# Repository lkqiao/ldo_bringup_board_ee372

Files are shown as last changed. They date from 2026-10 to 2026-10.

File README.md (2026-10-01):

# ldo_bringup_board_ee372

LDO bring up PCB for EE372.

- 20 µF / 390 mΩ RC dominant pole compensation at VOUT
- 0.1 µF cap at the NR pin for bandgap reference noise filtering
- Switch on the MD pin to toggle between high power and low power modes

## Project libraries

Both libraries are registered in the project-local `sym-lib-table` /
`fp-lib-table` under the nickname `ldo_bringup_board_ee372`, via
`${KIPRJMOD}`, so they resolve on any clone without per-machine setup.

| File | Contents |
|---|---|
| `ldo_bringup_board_ee372.kicad_sym` | `LDO_DualMode_BGR_EE372` — 32-pin symbol + EP |
| `ldo_bringup_board_ee372.pretty/` | `QFN-32-1EP_7x7mm_P0.65mm_EP5.1x5.1mm_QuikPak` |

### Package

Quik-Pak **QP-QFN32-7MM-.65MM**, open-cavity QFN-32, rev A2. The numbers
come from the EE372B PCB Design Guidelines (Fall 2026, section 2), the
Quik-Pak mechanical drawing `QP-QFN7X7-32-650 PACKAGE.pdf` and the bonding
drawing `QP-QFN7X7-32-650 BONDING.dwg`.

| Parameter | Value | Source |
|---|---|---|
| Body | 7.000 x 7.000 mm, 0.800 tall | guidelines 2.1, package drawing |
| Leads | 32 (8/side), pitch 0.650 mm | guidelines 2.1, package drawing |
| Lead width x length | 0.300 x 0.380 mm | package drawing, bottom view |
| Lead-centre span per side | 4.550 mm | package drawing, bottom view |
| Exposed paddle (bottom) | 5.100 x 5.100 mm | package drawing, bottom view |
| Die attach surface (in the cavity) | 5.300 x 5.300 mm | bonding drawing note 3; not the land size |
| Pin-1 ID | 0.400 x 45 deg chamfer | package drawing, top view |

### Footprint

`QFN-32-1EP_7x7mm_P0.65mm_EP5.1x5.1mm_QuikPak`, checked against every
requirement in guidelines section 2.2.

| Pad size | Pitch | EP land | Courtyard |
|---|---|---|---|
| 0.30 x 0.85 mm | 0.65 mm | 5.10 x 5.10 mm | 8.26 x 8.26 mm |

- Lands extend 0.375 mm past the body edge and sit 0.475 mm from the EP land.
- 9 thermal vias, 0.3 mm drill, numbered 33 with the EP. They are tented on
  both sides because the EP has no full mask opening. Instead, 16 mask windows
  sit exactly over the 16 paste windows.
- EP paste is a 4x4 window pane at 52.5% coverage.
- Pin 1 is marked on silkscreen with a dot and a 0.4 mm chamfered corner.
- The 3D model is KiCad's stock `QFN-32-1EP_7x7mm_P0.65mm_EP5.46x5.46mm.step`,
  0.9 mm tall with a closed top. It is only for renders.

### Pinout

From the die pad map. Package pin 1 = the first pad down the **left** side,
i.e. the die orientation mark aligned to the package `PIN #1 ID`. Numbering
then runs CCW: left T→B (1-8), bottom L→R (9-16), right B→T (17-24),
top R→L (25-32). Pin 33 is the exposed pad.

| | | | |
|---|---|---|---|
| 1 VSS | 9 VDD | 17 VSS | 25 VDD |
| 2 VSS | 10 VSS | 18 VSS | 26 VDD |
| 3 VSS | 11 VSS | 19 VSS | 27 VDD |
| 4 VDD | 12 VSS | 20 VSS | 28 VSS |
| 5 IBIAS | 13 VSS | 21 VOUT | 29 MD |
| 6 VSS | 14 VSS | 22 VOUT | 30 NR |
| 7 VSS | 15 VSS | 23 VSS | 31 VSS |
| 8 VDD | 16 VDD | 24 VDD | 32 VDD |

Census: 18 × VSS, 9 × VDD, 2 × VOUT, 1 × MD, 1 × NR, 1 × IBIAS = 32.

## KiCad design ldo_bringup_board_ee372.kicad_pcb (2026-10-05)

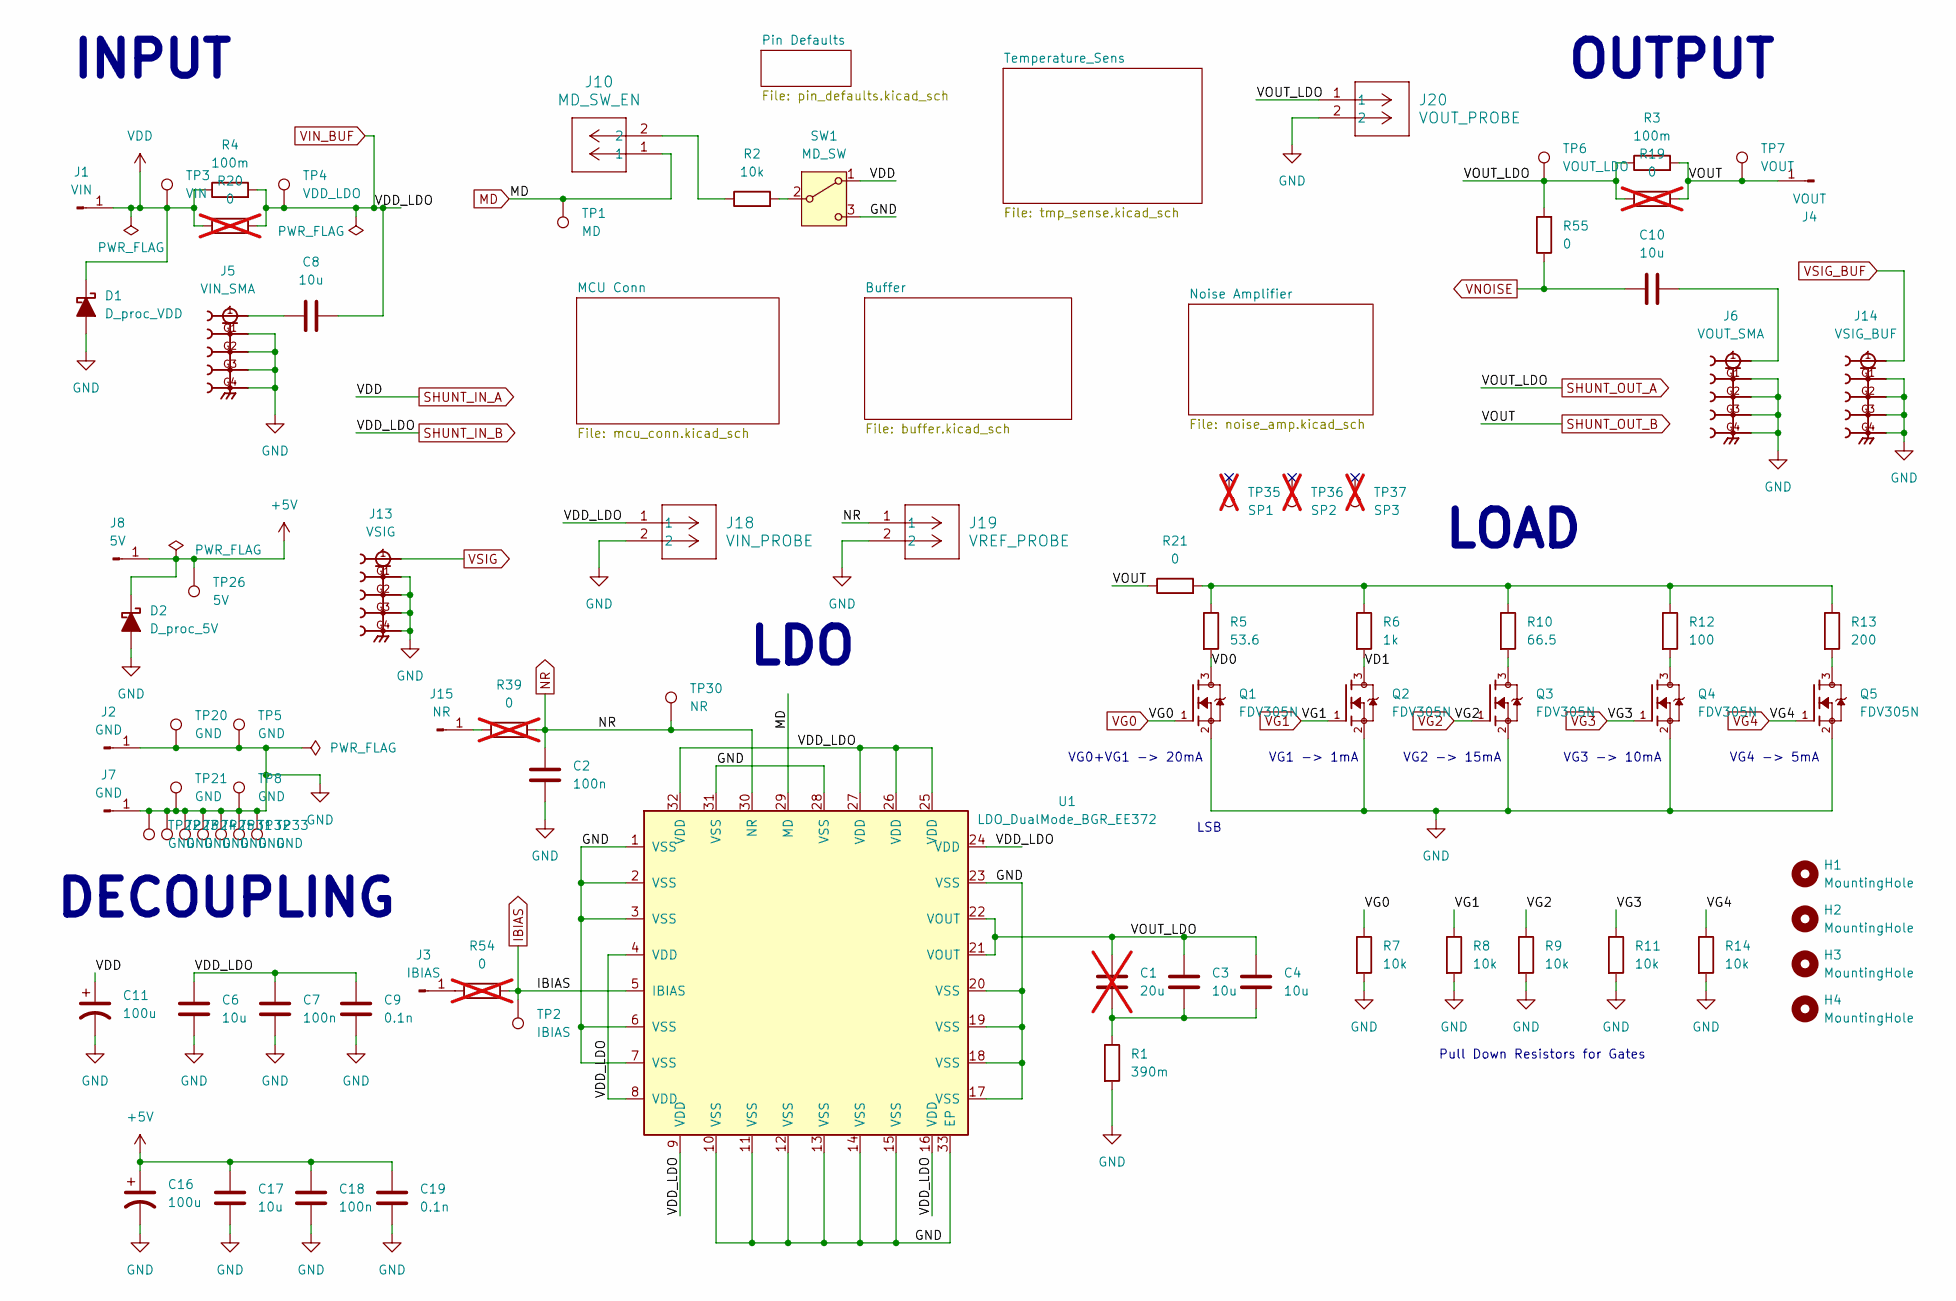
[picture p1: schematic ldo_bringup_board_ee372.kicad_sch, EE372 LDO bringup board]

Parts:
C1: 20u; C_1812_4532Metric_Pad1.57x3.40mm_HandSolder; Manufacturer Part Number C1812C206K3RLCTU; not fitted
C2, C7, C18: 100n; C_0805_2012Metric_Pad1.18x1.45mm_HandSolder; Manufacturer Part Number CL21B104KBCNNNC
C3, C4: 10u; C_1206_3216Metric_Pad1.33x1.80mm_HandSolder; Manufacturer Part Number C1206C106J3RACAUTO
C6, C8, C10, C17: 10u; C_1206_3216Metric_Pad1.33x1.80mm_HandSolder; Manufacturer Part Number GRM319R61E106KA12D
C9, C19: 0.1n; C_0805_2012Metric_Pad1.18x1.45mm_HandSolder; Manufacturer Part Number CL21C101JBANNNC
C11, C16: 100u; CP_Radial_D6.3mm_P2.50mm; Manufacturer Part Number EEU-FC1E101S
D1: D_proc_VDD; D_SMA_Handsoldering; Manufacturer Part Number B120-13-F
D2: D_proc_5V; D_SMA_Handsoldering; Manufacturer Part Number B120-13-F
H1, H2, H3, H4: MountingHole; MountingHole_3.2mm_M3
J1: VIN; CalTest_CT3151SP; Manufacturer Part Number CT3151SP-2
J2, J7: GND; CalTest_CT3151SP; Manufacturer Part Number CT3151SP-0
J3: IBIAS; CalTest_CT3151SP; Manufacturer Part Number CT3151SP-9
J4: VOUT; CalTest_CT3151SP; Manufacturer Part Number CT3151SP-4
J5: VIN_SMA; SMA_Samtec_SMA-J-P-H-ST-EM1_EdgeMount_G; Manufacturer Part Number SMA-J-P-H-ST-EM1
J6: VOUT_SMA; SMA_Samtec_SMA-J-P-H-ST-EM1_EdgeMount_G; Manufacturer Part Number SMA-J-P-H-ST-EM1
J8: 5V; CalTest_CT3151SP; Manufacturer Part Number CT3151SP-2
J10: MD_SW_EN; CONN_PxC02S_SUL; Manufacturer Part Number PEC02SAAN
J13: VSIG; SMA_Samtec_SMA-J-P-H-ST-EM1_EdgeMount_G; Manufacturer Part Number SMA-J-P-H-ST-EM1
J14: VSIG_BUF; SMA_Samtec_SMA-J-P-H-ST-EM1_EdgeMount_G; Manufacturer Part Number SMA-J-P-H-ST-EM1
J15: NR; CalTest_CT3151SP; Manufacturer Part Number CT3151SP-2
J18: VIN_PROBE; CONN_PxC02S_SUL; Manufacturer Part Number PEC02SAAN
J19: VREF_PROBE; CONN_PxC02S_SUL; Manufacturer Part Number PEC02SAAN
J20: VOUT_PROBE; CONN_PxC02S_SUL; Manufacturer Part Number PEC02SAAN
Q1, Q2, Q3, Q4, Q5: FDV305N; SOT95P240X111-3N; Manufacturer Part Number FDV305N
R1: 390m; R_0805_2012Metric_Pad1.20x1.40mm_HandSolder; Manufacturer Part Number ERJ-6BQFR39V
R2, R7, R8, R9, R11, R14: 10k; R_0805_2012Metric_Pad1.20x1.40mm_HandSolder; Manufacturer Part Number RC0805FR-0710KL
R3, R4: 100m; R_0805_2012Metric_Pad1.20x1.40mm_HandSolder; Manufacturer Part Number ERJ-6DSFR10V
R5: 53.6; R_0805_2012Metric_Pad1.20x1.40mm_HandSolder; Manufacturer Part Number RC0805FR-0753R6L
R6: 1k; R_0805_2012Metric_Pad1.20x1.40mm_HandSolder; Manufacturer Part Number RC0805FR-071KL
R10: 66.5; R_0805_2012Metric_Pad1.20x1.40mm_HandSolder; Manufacturer Part Number RC0805FR-0766R5L
R12: 100; R_0805_2012Metric_Pad1.20x1.40mm_HandSolder; Manufacturer Part Number RC0805FR-07100RL
R13: 200; R_0805_2012Metric_Pad1.20x1.40mm_HandSolder; Manufacturer Part Number RC0805FR-07200RL
R19, R20, R39, R54: 0; R_0805_2012Metric_Pad1.20x1.40mm_HandSolder; Manufacturer Part Number CRCW08050000Z0EAHP; not fitted
R21, R55: 0; R_0805_2012Metric_Pad1.20x1.40mm_HandSolder; Manufacturer Part Number CRCW08050000Z0EAHP
SW1: MD_SW; SW_SPDT_CK_JS102011SAQN; Manufacturer Part Number JS102011SAQN
TP1: MD; TestPoint_Keystone_5005-5009_Compact; Manufacturer Part Number 5005
TP2: IBIAS; TestPoint_Keystone_5005-5009_Compact; Manufacturer Part Number 5005
TP3: VIN; TestPoint_Keystone_5005-5009_Compact; Manufacturer Part Number 5005
TP4: VDD_LDO; TestPoint_Keystone_5005-5009_Compact; Manufacturer Part Number 5005
TP5, TP8, TP20, TP21, TP22, TP23, TP24, TP25, TP31, TP32, TP33: GND; TestPoint_Keystone_5005-5009_Compact; Manufacturer Part Number 5006
TP6: VOUT_LDO; TestPoint_Keystone_5005-5009_Compact; Manufacturer Part Number 5005
TP7: VOUT; TestPoint_Keystone_5005-5009_Compact; Manufacturer Part Number 5005
TP26: 5V; TestPoint_Keystone_5005-5009_Compact; Manufacturer Part Number 5005
TP30: NR; TestPoint_Keystone_5005-5009_Compact; Manufacturer Part Number 5005
TP35: SP1; TestPoint_Keystone_5005-5009_Compact; Manufacturer Part Number 5006; not fitted
TP36: SP2; TestPoint_Keystone_5005-5009_Compact; Manufacturer Part Number 5006; not fitted
TP37: SP3; TestPoint_Keystone_5005-5009_Compact; Manufacturer Part Number 5006; not fitted
U1: LDO_DualMode_BGR_EE372; QFN-32-1EP_7x7mm_P0.65mm_EP5.1x5.1mm_QuikPak

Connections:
+5V: C16.1, C17.1, C18.1, C19.1, D2.1 (K), J8.1 (Pin_1_1), TP26.1 (1_1); also elsewhere on the board
/VD0: Q1.3, R5.2
/VD1: Q2.3, R6.2
GND: C2.2, C6.2, C7.2, C9.2, C11.2, C16.2, C17.2, C18.2, C19.2, D1.2 (A), D2.2 (A), J2.1 (Pin_1_1), J5.G1, J5.G2, J5.G3, J5.G4, J6.G1, J6.G2, J6.G3, J6.G4, J7.1 (Pin_1_1), J13.G1, J13.G2, J13.G3, J13.G4, J14.G1, J14.G2, J14.G3, J14.G4, J18.2, J19.2, J20.2, Q1.2, Q2.2, Q3.2, Q4.2, Q5.2, R1.2, R7.2, R8.2, R9.2, R11.2, R14.2, SW1.3 (C), TP5.1 (1_1), TP8.1 (1_1), TP20.1 (1_1), TP21.1 (1_1), TP22.1 (1_1), TP23.1 (1_1), TP24.1 (1_1), TP25.1 (1_1), TP31.1 (1_1), TP32.1 (1_1), TP33.1 (1_1), U1.1 (VSS), U1.2 (VSS), U1.3 (VSS), U1.6 (VSS), U1.7 (VSS), U1.10 (VSS), U1.11 (VSS), U1.12 (VSS), U1.13 (VSS), U1.14 (VSS), U1.15 (VSS), U1.17 (VSS), U1.18 (VSS), U1.19 (VSS), U1.20 (VSS), U1.23 (VSS), U1.28 (VSS), U1.31 (VSS), U1.33 (EP); also elsewhere on the board
IBIAS: R54.2, TP2.1 (1_1), U1.5 (IBIAS); also elsewhere on the board
MD: J10.1, TP1.1 (1_1), U1.29 (MD); also elsewhere on the board
NR: C2.1, J19.1, R39.2, TP30.1 (1_1), U1.30 (NR); also elsewhere on the board
unnamed: C1.2, C3.2, C4.2, R1.1
unnamed: C8.1, J5.1
unnamed: C10.2, J6.1
unnamed: J3.1 (Pin_1_1), R54.1
unnamed: J10.2, R2.1
unnamed: J15.1 (Pin_1_1), R39.1
unnamed: Q3.3, R10.2
unnamed: Q4.3, R12.2
unnamed: Q5.3, R13.2
unnamed: R5.1, R6.1, R10.1, R12.1, R13.1, R21.2
unnamed: R2.2, SW1.2 (B)
SHUNT_IN_A: C11.1, D1.1 (K), J1.1 (Pin_1_1), R4.1, R20.1, SW1.1 (A), TP3.1 (1_1); also elsewhere on the board
SHUNT_IN_B: C6.1, C7.1, C8.2, C9.1, J18.1, R4.2, R20.2, TP4.1 (1_1), U1.4 (VDD), U1.8 (VDD), U1.9 (VDD), U1.16 (VDD), U1.24 (VDD), U1.25 (VDD), U1.26 (VDD), U1.27 (VDD), U1.32 (VDD); also elsewhere on the board
SHUNT_OUT_A: C1.1, C3.1, C4.1, J20.1, R3.1, R19.1, R55.2, TP6.1 (1_1), U1.21 (VOUT), U1.22 (VOUT); also elsewhere on the board
SHUNT_OUT_B: J4.1 (Pin_1_1), R3.2, R19.2, R21.1, TP7.1 (1_1); also elsewhere on the board
VG0: Q1.1, R7.1; also elsewhere on the board
VG1: Q2.1, R8.1; also elsewhere on the board
VG2: Q3.1, R9.1; also elsewhere on the board
VG3: Q4.1, R11.1; also elsewhere on the board
VG4: Q5.1, R14.1; also elsewhere on the board
VNOISE: C10.1, R55.1; also elsewhere on the board
VSIG: J13.1; also elsewhere on the board
VSIG_BUF: J14.1; also elsewhere on the board

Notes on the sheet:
OUTPUT
VG0+VG1 -> 20mA
VG3 -> 10mA
LSB
Pull Down Resistors for Gates
VG4 -> 5mA
LOAD
VG2 -> 15mA
DECOUPLING
LDO
VG1 -> 1mA
INPUT

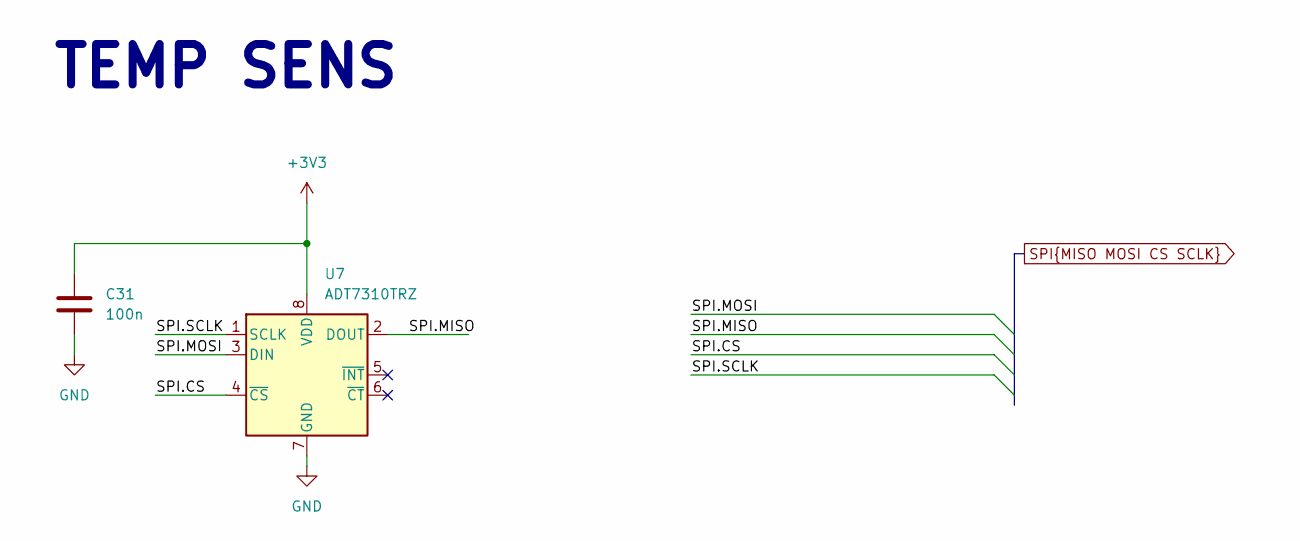
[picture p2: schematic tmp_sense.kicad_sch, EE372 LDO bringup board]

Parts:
C31: 100n; C_0805_2012Metric_Pad1.18x1.45mm_HandSolder; Manufacturer Part Number CL21B104KBCNNNC
U7: ADT7310TRZ; SOIC-8_3.9x4.9mm_P1.27mm; Manufacturer Part Number ADT7310TRZ

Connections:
+3V3: C31.1, U7.8 (VDD); also elsewhere on the board
GND: C31.2, U7.7 (GND); also elsewhere on the board
SPI.CS: U7.4 (~CS); also elsewhere on the board
SPI.MISO: U7.2 (DOUT); also elsewhere on the board
SPI.MOSI: U7.3 (DIN); also elsewhere on the board
SPI.SCLK: U7.1 (SCLK); also elsewhere on the board

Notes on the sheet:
TEMP SENS

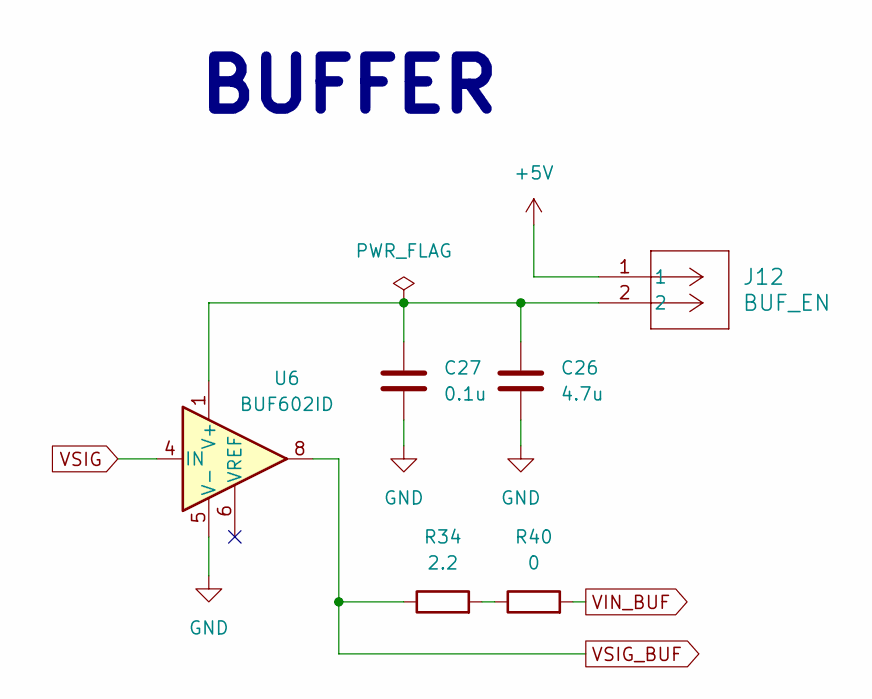
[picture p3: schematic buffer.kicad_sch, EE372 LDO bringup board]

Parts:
C26: 4.7u; C_0805_2012Metric_Pad1.18x1.45mm_HandSolder; Manufacturer Part Number CL21B475KAFNNNE
C27: 0.1u; C_0805_2012Metric_Pad1.18x1.45mm_HandSolder; Manufacturer Part Number CL21B104KBCNNNC
J12: BUF_EN; CONN_PxC02S_SUL; Manufacturer Part Number PEC02SAAN
R34: 2.2; R_0603_1608Metric_Pad0.98x0.95mm_HandSolder; Manufacturer Part Number ERJ-3RQF2R2V
R40: 0; R_0603_1608Metric_Pad0.98x0.95mm_HandSolder; Manufacturer Part Number CRCW06030000Z0EAHP
U6: BUF602ID; SOIC-8_3.9x4.9mm_P1.27mm; Manufacturer Part Number BUF602ID

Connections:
+5V: J12.1; also elsewhere on the board
GND: C26.1, C27.1, U6.5 (V-); also elsewhere on the board
unnamed: R34.2, R40.1
unnamed: C26.2, C27.2, J12.2, U6.1 (V+)
SHUNT_IN_B: R40.2; also elsewhere on the board
VSIG: U6.4 (IN); also elsewhere on the board
VSIG_BUF: R34.1, U6.8; also elsewhere on the board

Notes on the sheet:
BUFFER

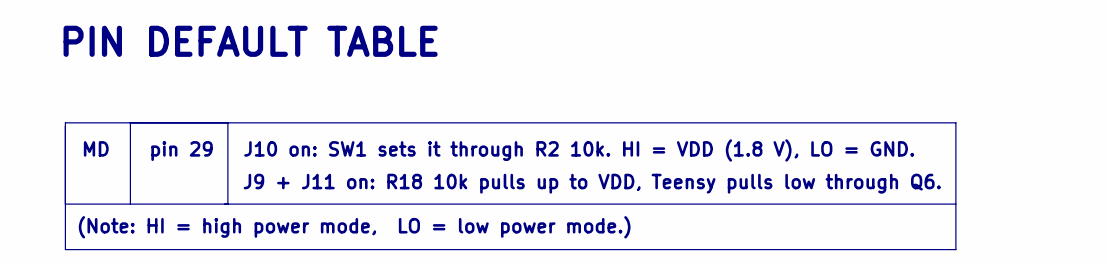
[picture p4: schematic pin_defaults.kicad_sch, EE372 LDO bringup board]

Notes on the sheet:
J9 + J11 on: R18 10k pulls up to VDD, Teensy pulls low through Q6.
(Note: HI = high power mode, LO = low power mode.)
PIN DEFAULT TABLE
MD pin 29 J10 on: SW1 sets it through R2 10k. HI = VDD (1.8 V), LO = GND.

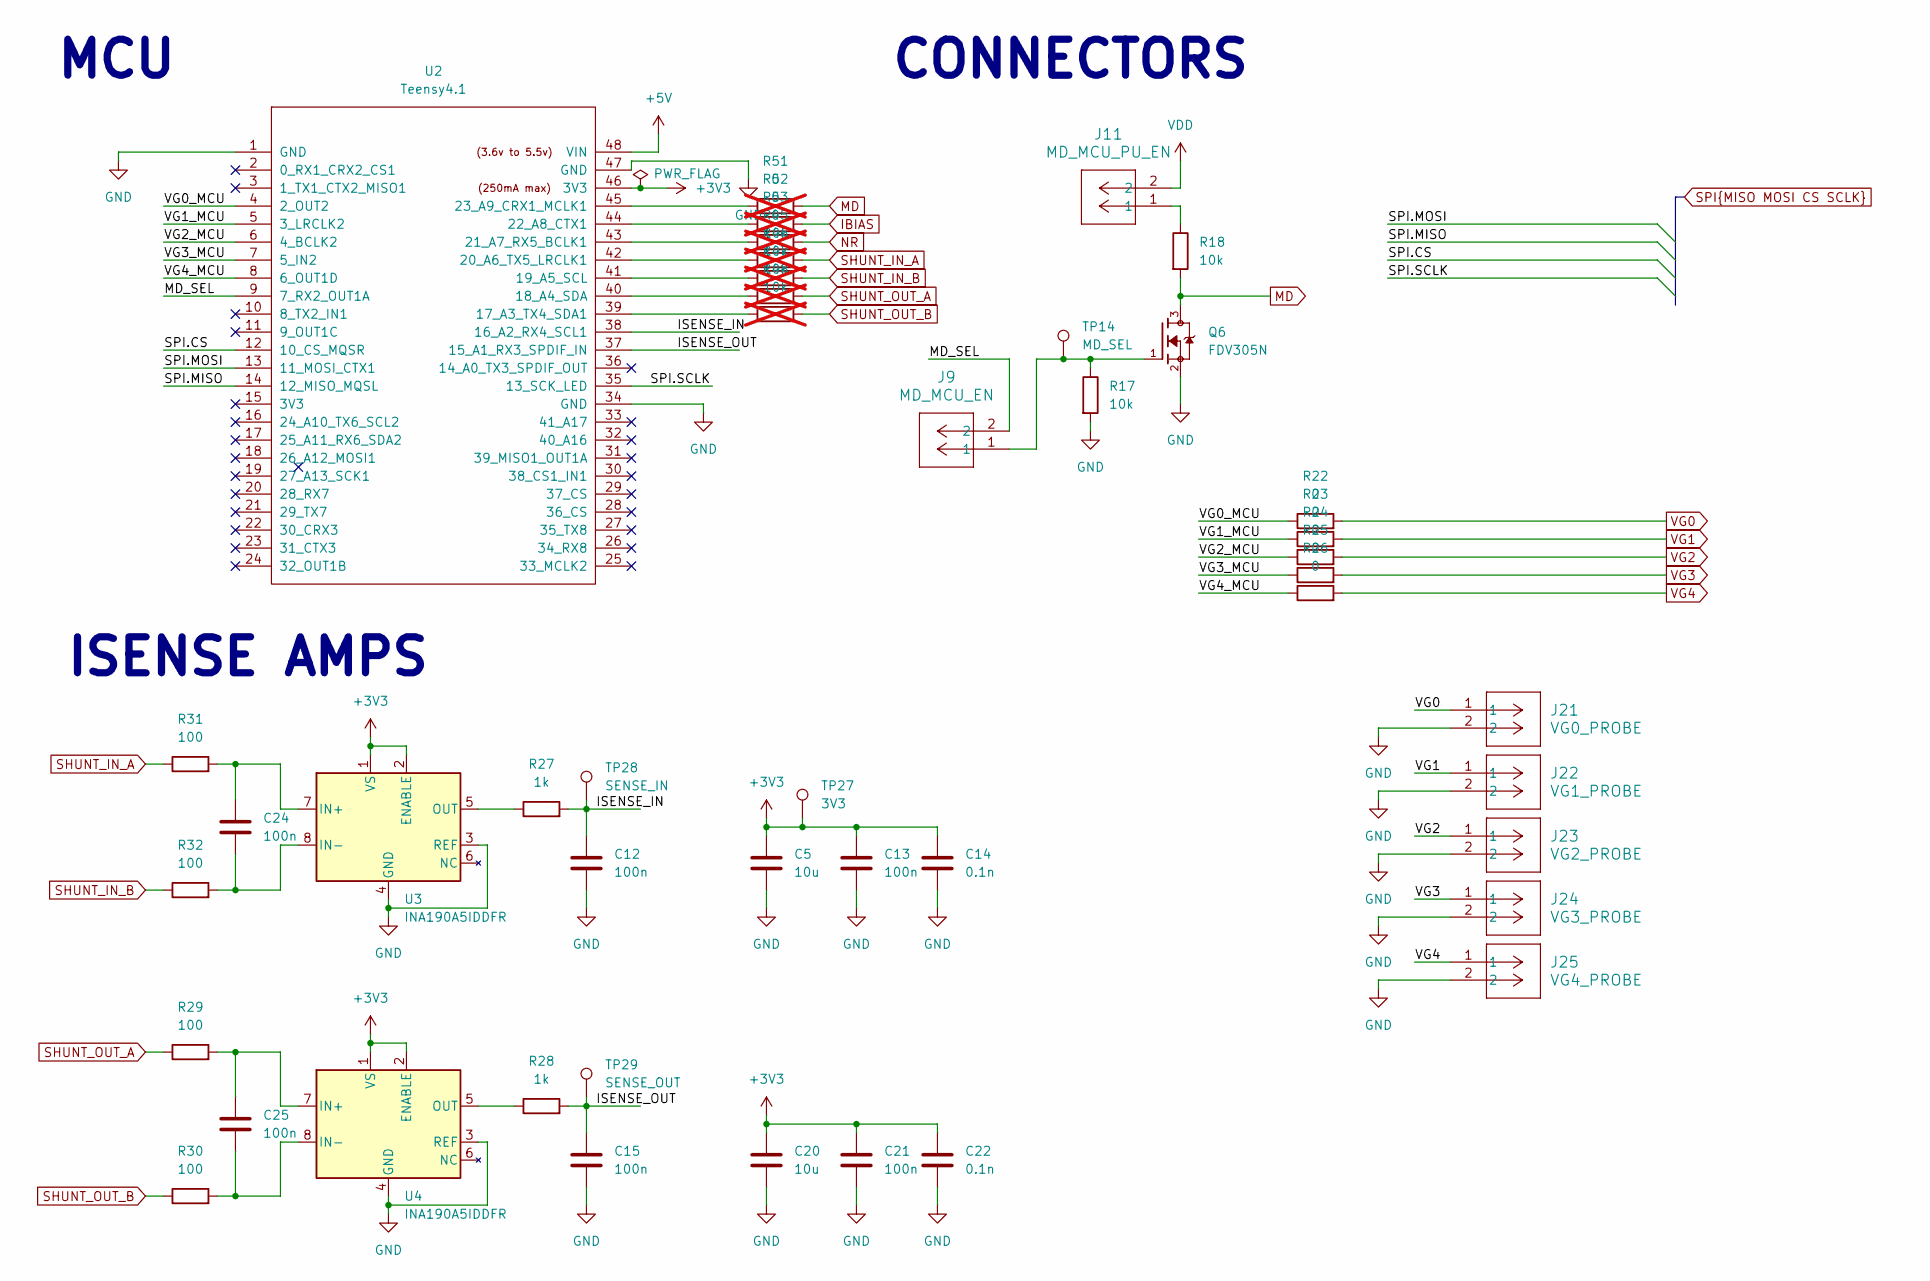
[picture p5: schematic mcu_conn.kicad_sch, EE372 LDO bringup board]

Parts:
C5, C20: 10u; C_1206_3216Metric_Pad1.33x1.80mm_HandSolder; Manufacturer Part Number GRM319R61E106KA12D
C12, C13, C15, C21, C24, C25: 100n; C_0805_2012Metric_Pad1.18x1.45mm_HandSolder; Manufacturer Part Number CL21B104KBCNNNC
C14, C22: 0.1n; C_0805_2012Metric_Pad1.18x1.45mm_HandSolder; Manufacturer Part Number CL21C101JBANNNC
J9: MD_MCU_EN; CONN_PxC02S_SUL; Manufacturer Part Number PEC02SAAN
J11: MD_MCU_PU_EN; CONN_PxC02S_SUL; Manufacturer Part Number PEC02SAAN
J21: VG0_PROBE; CONN_PxC02S_SUL; Manufacturer Part Number PEC02SAAN
J22: VG1_PROBE; CONN_PxC02S_SUL; Manufacturer Part Number PEC02SAAN
J23: VG2_PROBE; CONN_PxC02S_SUL; Manufacturer Part Number PEC02SAAN
J24: VG3_PROBE; CONN_PxC02S_SUL; Manufacturer Part Number PEC02SAAN
J25: VG4_PROBE; CONN_PxC02S_SUL; Manufacturer Part Number PEC02SAAN
Q6: FDV305N; SOT95P240X111-3N; Manufacturer Part Number FDV305N
R17, R18: 10k; R_0603_1608Metric_Pad0.98x0.95mm_HandSolder; Manufacturer Part Number RC0603FR-0710KL
R22, R23, R24, R25, R26: 0; R_0603_1608Metric_Pad0.98x0.95mm_HandSolder; Manufacturer Part Number CRCW06030000Z0EAHP
R27, R28: 1k; R_0603_1608Metric_Pad0.98x0.95mm_HandSolder; Manufacturer Part Number RC0603FR-071KL
R29, R30, R31, R32: 100; R_0603_1608Metric_Pad0.98x0.95mm_HandSolder; Manufacturer Part Number ERJ-3EKF1000V
R45, R46, R47, R48: 10k; R_0805_2012Metric_Pad1.20x1.40mm_HandSolder; Manufacturer Part Number RC0805FR-0710KL; not fitted
R51, R52, R53: 0; R_0603_1608Metric_Pad0.98x0.95mm_HandSolder; Manufacturer Part Number CRCW06030000Z0EAHP; not fitted
TP14: MD_SEL; TestPoint_Keystone_5005-5009_Compact; Manufacturer Part Number 5005
TP27: 3V3; TestPoint_Keystone_5005-5009_Compact; Manufacturer Part Number 5005
TP28: SENSE_IN; TestPoint_Keystone_5005-5009_Compact; Manufacturer Part Number 5005
TP29: SENSE_OUT; TestPoint_Keystone_5005-5009_Compact; Manufacturer Part Number 5005
U2: Teensy4.1; Teensy41_Sockets
U3, U4: INA190A5IDDFR; TSOT-23-8_HandSoldering; Manufacturer Part Number INA190A5IDDFR

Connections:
+3V3: C5.1, C13.1, C14.1, C20.1, C21.1, C22.1, TP27.1 (1_1), U2.46 (3V3), U3.1 (VS), U3.2 (ENABLE), U4.1 (VS), U4.2 (ENABLE); also elsewhere on the board
+5V: U2.48 (VIN); also elsewhere on the board
/MCU Conn/ISENSE_IN: C12.1, R27.2, TP28.1 (1_1), U2.38 (16_A2_RX4_SCL1)
/MCU Conn/ISENSE_OUT: C15.1, R28.2, TP29.1 (1_1), U2.37 (15_A1_RX3_SPDIF_IN)
/MCU Conn/MD_SEL: J9.2, U2.9 (7_RX2_OUT1A)
/MCU Conn/VG0_MCU: R22.1, U2.4 (2_OUT2)
/MCU Conn/VG1_MCU: R23.1, U2.5 (3_LRCLK2)
/MCU Conn/VG2_MCU: R24.1, U2.6 (4_BCLK2)
/MCU Conn/VG3_MCU: R25.1, U2.7 (5_IN2)
/MCU Conn/VG4_MCU: R26.1, U2.8 (6_OUT1D)
GND: C5.2, C12.2, C13.2, C14.2, C15.2, C20.2, C21.2, C22.2, J21.2, J22.2, J23.2, J24.2, J25.2, Q6.2, R17.2, U2.1 (GND), U2.34 (GND), U2.47 (GND), U3.3 (REF), U3.4 (GND), U4.3 (REF), U4.4 (GND); also elsewhere on the board
IBIAS: R52.2; also elsewhere on the board
MD: Q6.3, R18.2, R51.2; also elsewhere on the board
NR: R53.2; also elsewhere on the board
unnamed: J9.1, Q6.1, R17.1, TP14.1 (1_1)
unnamed: J11.1, R18.1
unnamed: R48.1, U2.39 (17_A3_TX4_SDA1)
unnamed: R47.1, U2.40 (18_A4_SDA)
unnamed: R46.1, U2.41 (19_A5_SCL)
unnamed: R45.1, U2.42 (20_A6_TX5_LRCLK1)
unnamed: R53.1, U2.43 (21_A7_RX5_BCLK1)
unnamed: R52.1, U2.44 (22_A8_CTX1)
unnamed: R51.1, U2.45 (23_A9_CRX1_MCLK1)
unnamed: C24.1, R31.2, U3.7 (IN+)
unnamed: C24.2, R32.2, U3.8 (IN-)
unnamed: R27.1, U3.5 (OUT)
unnamed: C25.1, R29.2, U4.7 (IN+)
unnamed: C25.2, R30.2, U4.8 (IN-)
unnamed: R28.1, U4.5 (OUT)
SHUNT_IN_A: J11.2, R31.1, R45.2; also elsewhere on the board
SHUNT_IN_B: R32.1, R46.2; also elsewhere on the board
SHUNT_OUT_A: R29.1, R47.2; also elsewhere on the board
SHUNT_OUT_B: R30.1, R48.2; also elsewhere on the board
SPI.CS: U2.12 (10_CS_MQSR); also elsewhere on the board
SPI.MISO: U2.14 (12_MISO_MQSL); also elsewhere on the board
SPI.MOSI: U2.13 (11_MOSI_CTX1); also elsewhere on the board
SPI.SCLK: U2.35 (13_SCK_LED); also elsewhere on the board
VG0: J21.1, R22.2; also elsewhere on the board
VG1: J22.1, R23.2; also elsewhere on the board
VG2: J23.1, R24.2; also elsewhere on the board
VG3: J24.1, R25.2; also elsewhere on the board
VG4: J25.1, R26.2; also elsewhere on the board

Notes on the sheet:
CONNECTORS
MCU
ISENSE AMPS

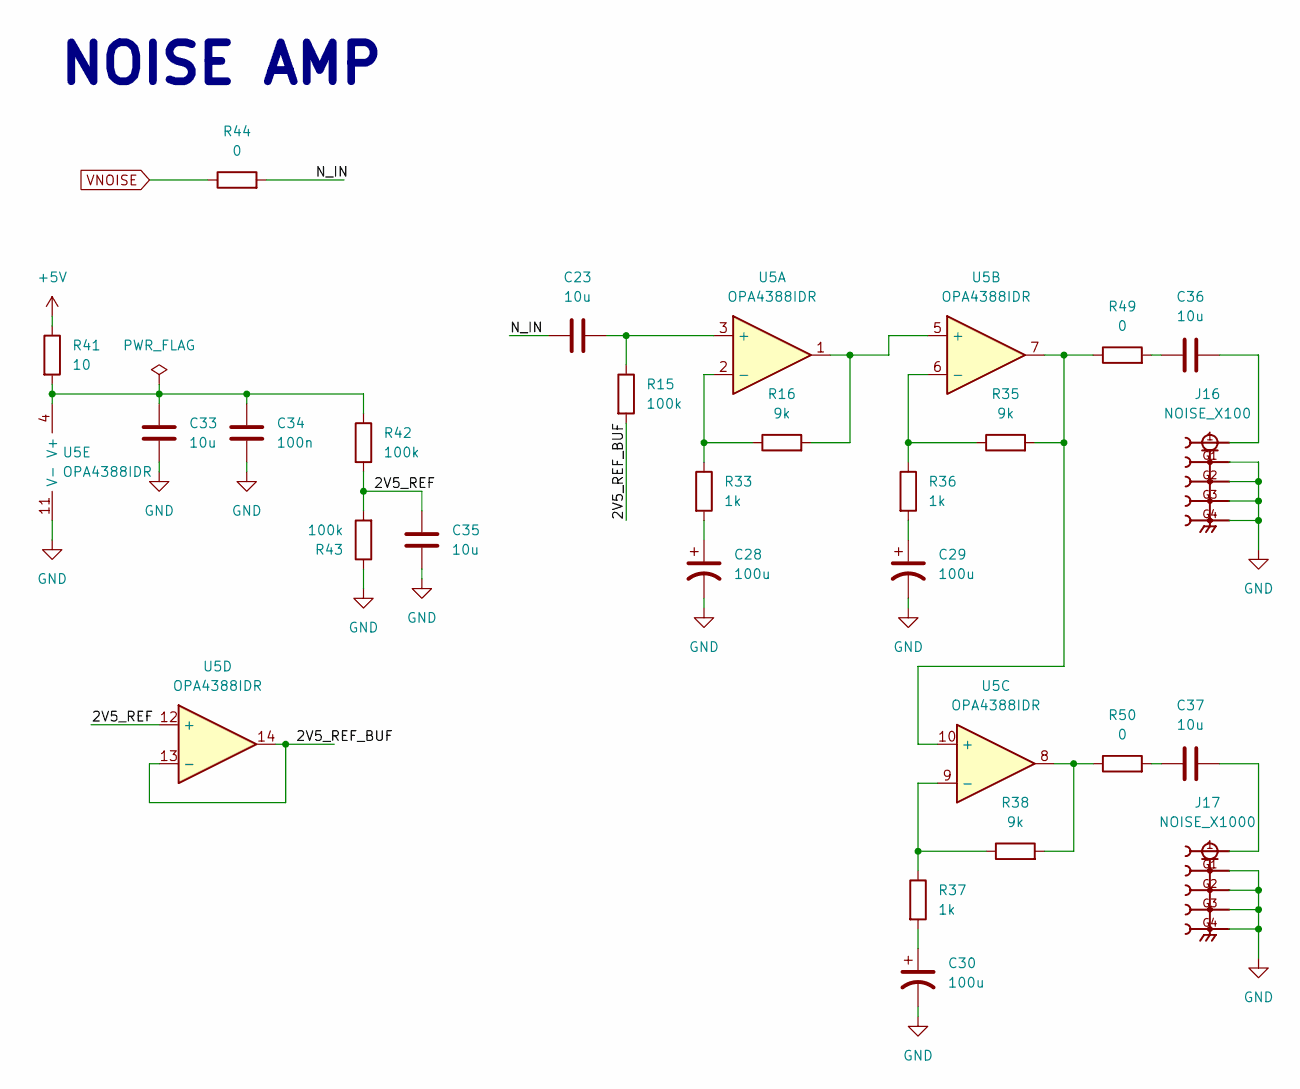
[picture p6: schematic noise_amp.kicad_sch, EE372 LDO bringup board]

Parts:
C23, C33, C35, C36, C37: 10u; C_1206_3216Metric_Pad1.33x1.80mm_HandSolder; Manufacturer Part Number GRM319R61E106KA12D
C28, C29, C30: 100u; CP_Radial_D6.3mm_P2.50mm; Manufacturer Part Number EEU-FC1E101S
C34: 100n; C_0805_2012Metric_Pad1.18x1.45mm_HandSolder; Manufacturer Part Number CL21B104KBCNNNC
J16: NOISE_X100; SMA_Samtec_SMA-J-P-H-ST-EM1_EdgeMount_G; Manufacturer Part Number SMA-J-P-H-ST-EM1
J17: NOISE_X1000; SMA_Samtec_SMA-J-P-H-ST-EM1_EdgeMount_G; Manufacturer Part Number SMA-J-P-H-ST-EM1
R15, R42, R43: 100k; R_0603_1608Metric_Pad0.98x0.95mm_HandSolder; Manufacturer Part Number RC0603FR-07100KL
R16, R35, R38: 9k; R_0805_2012Metric_Pad1.20x1.40mm_HandSolder; Manufacturer Part Number RT0805BRE079KL
R33, R36, R37: 1k; R_0603_1608Metric_Pad0.98x0.95mm_HandSolder; Manufacturer Part Number RC0603FR-071KL
R41: 10; R_0603_1608Metric_Pad0.98x0.95mm_HandSolder; Manufacturer Part Number ERJ-3EKF10R0V
R44: 0; R_0805_2012Metric_Pad1.20x1.40mm_HandSolder; Manufacturer Part Number CRCW08050000Z0EAHP
R49, R50: 0; R_0603_1608Metric_Pad0.98x0.95mm_HandSolder; Manufacturer Part Number CRCW06030000Z0EAHP
U5: OPA4388IDR; SOIC-14_3.9x8.7mm_P1.27mm; Manufacturer Part Number OPA4388IDR

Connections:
+5V: R41.1; also elsewhere on the board
/Noise Amplifier/2V5_REF: C35.1, R42.2, R43.2, U5.12 (+)
/Noise Amplifier/2V5_REF_BUF: R15.2, U5.13 (-), U5.14
/Noise Amplifier/N_IN: C23.2, R44.2
GND: C28.2, C29.2, C30.2, C33.2, C34.2, C35.2, J16.G1, J16.G2, J16.G3, J16.G4, J17.G1, J17.G2, J17.G3, J17.G4, R43.1, U5.11 (V-); also elsewhere on the board
unnamed: C28.1, R33.2
unnamed: C29.1, R36.2
unnamed: C30.1, R37.2
unnamed: C36.1, R49.2
unnamed: C36.2, J16.1
unnamed: C37.1, R50.2
unnamed: C37.2, J17.1
unnamed: R38.2, R50.1, U5.8
unnamed: C23.1, R15.1, U5.3 (+)
unnamed: R16.1, R33.1, U5.2 (-)
unnamed: R16.2, U5.1, U5.5 (+)
unnamed: R35.1, R36.1, U5.6 (-)
unnamed: R35.2, R49.1, U5.7, U5.10 (+)
unnamed: R37.1, R38.1, U5.9 (-)
unnamed: C33.1, C34.1, R41.2, R42.1, U5.4 (V+)
VNOISE: R44.1; also elsewhere on the board

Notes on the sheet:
NOISE AMP

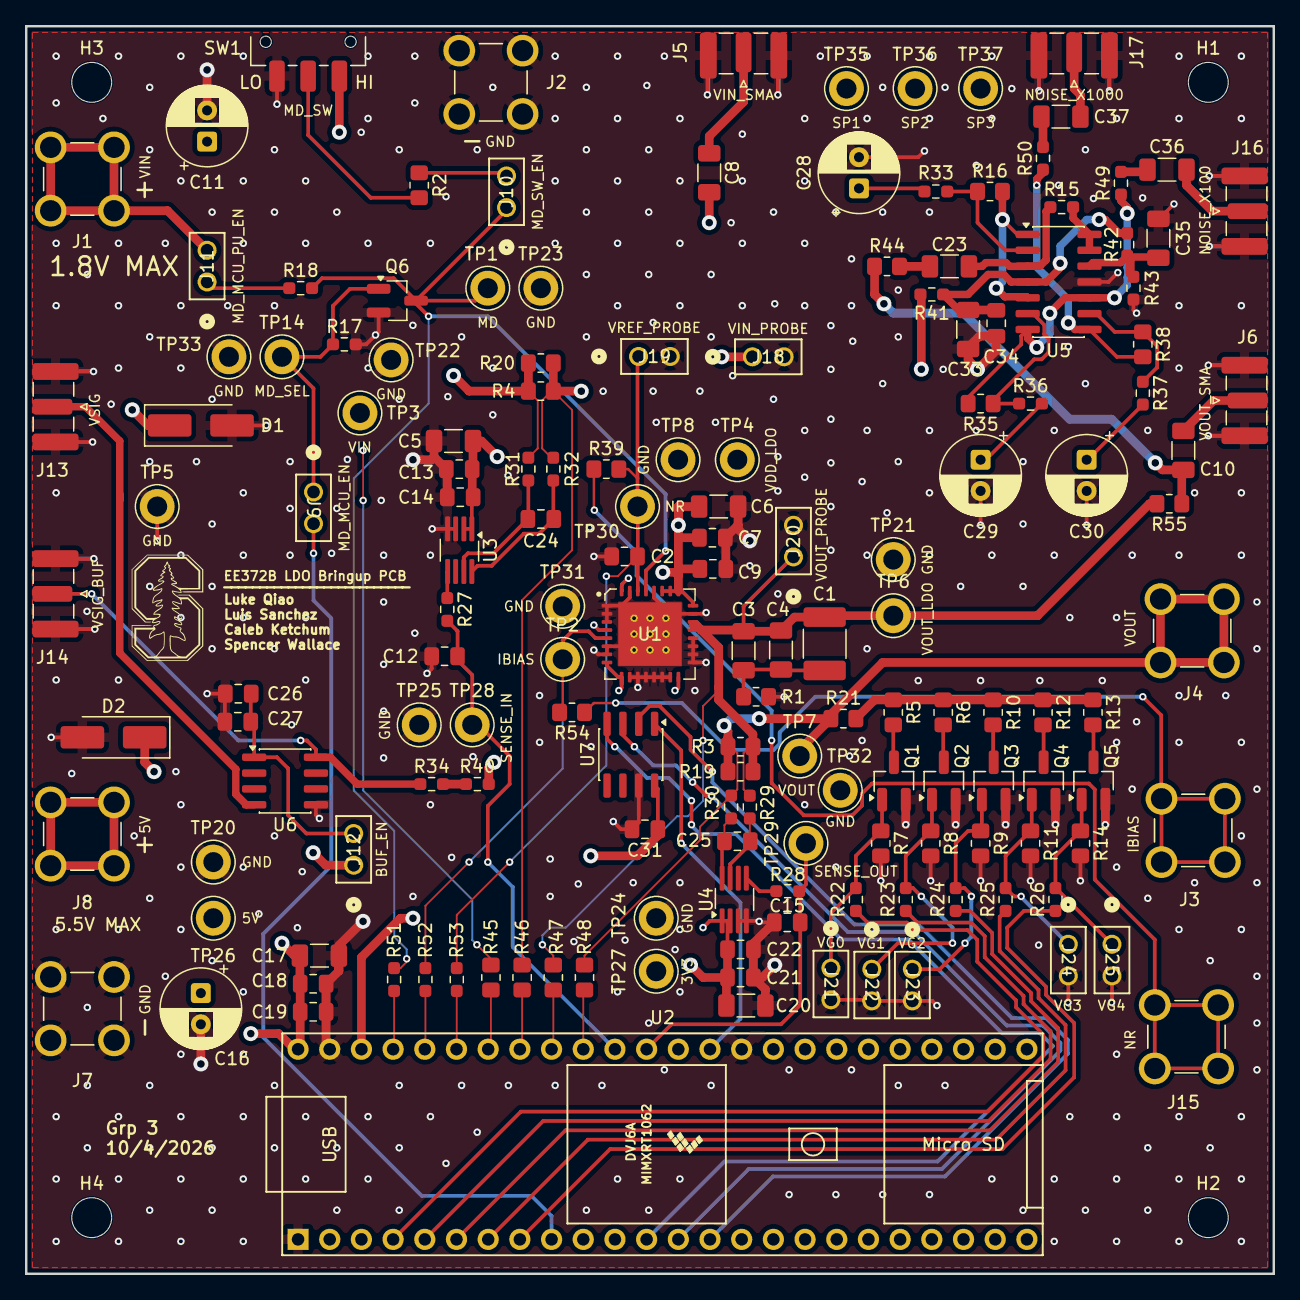
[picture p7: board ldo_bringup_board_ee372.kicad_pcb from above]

Board: 4 copper layers, 100.0 x 100.0 mm, 162 parts (0 on the bottom side), 78 nets.

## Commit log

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2026-08-02 Fix over-broad gitignore rules
    - Drop blanket *.xml (was silently ignoring vendor models, docs)
    - Drop production/ (hand-authored fab notes are source, not output)
    - Drop *.gbr/*.drl/*.gbrjob globs so archived fab packages are tracked
    - Drop ~*.* shotgun rule (KiCad 9 uses _autosave-*, not ~ prefix)
    - Document that footprints and 3D models are intentionally tracked
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2026-08-03 Add schematic title block and default ERC/DRC rules
    Fills in the sheet title block (project name, date, rev 0, authors).
    The .kicad_pro gains KiCad 9's default ERC pin map and severity settings,
    written out when the schematic editor first saved the sheet.
    No symbols placed yet — (lib_symbols) is still empty.
    [ldo_bringup_board_ee372.kicad_sch]
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2026-08-16 Capture full bringup schematic
    Place the remaining board components and wire the sheet:
    - J1 Screw_Terminal_01x04 - VDD, IBIAS, GND, GND
    - C1 20u output compensation cap
    - R1 390m series resistance setting the compensation zero
    - C2 0.1u BGR noise filter on NR
    - SW1 SW_SPDT mode select, switching MD between VDD and GND
    - VDD and GND power symbols
    All 33 pins of U1 are now connected across 7 nets. VOUT (pins 21+22)
    feeds the R1/C1 compensation leg to ground; the exposed pad (33) ties
    to GND.
    [ldo_bringup_board_ee372.kicad_sch]
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2026-08-16 Add C3/C4 as DNP parallel positions for the output cap
    Two 10u Device:C symbols in parallel with C1, sharing the same
    VOUT node and the same series R1 leg to ground. Both are marked
    DNP, so they are unpopulated footprints on the board and stay out
    of the BOM until the compensation bank is actually needed.
    VOUT label nudged to 179.07 to clear the new rail.
    [ldo_bringup_board_ee372.kicad_sch]
2026-08-27 Add C5, a 10 uF decoupling cap from VDD to GND
    C5.1 sits on VDD alongside J1.1 and the nine U1 supply pads; C5.2 goes to
    GND through a new power symbol. Closes the missing-bypass gap on the input
    rail.
    The .kicad_pro change is KiCad's own ngspice defaults block, written
    automatically when the project was opened. No settings were chosen by hand.
    [ldo_bringup_board_ee372.kicad_sch]
2026-08-27 Retype U1 pin 22 as passive in the symbol library
    Pins 21 and 22 are both VOUT and are tied together on the board, which is
    correct, but two power_out pins on one net is an ERC error. Making 22
    passive leaves 21 as the single driver and clears it. Electrically nothing
    changes; pin type only affects ERC.
    The schematic still holds its own cached copy of the symbol, so this does
    not take effect until Tools > Update Symbols from Library is run in
    Eeschema.
    Claude-Session: https://claude.ai/code/session_01VKJ9HuNquNDJoAhaeaEoF6
2026-08-27 Retype U1 pin 22 as passive in the schematic's cached symbol
    The schematic keeps its own copy of the symbol from placement time and does
    not re-read the library, so edfba3e alone left the ERC error in place. This
    applies the same one-word change to the cached copy, which also clears the
    resulting lib_symbol_mismatch.
    Pin type only. Verified by netlist export before and after: every net and
    every node is identical. ERC drops from 3 errors to 2 power_pin_not_driven.
    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
    [ldo_bringup_board_ee372.kicad_sch]
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2026-09-29 Rename the QFN-32 footprint to EP5.1x5.1mm and update the README
    The footprint's exposed pad is 5.1 mm since 919dac9, so the name now says
    so. Updated in every place it appears: the .kicad_mod filename and its
    footprint and Value names, the symbol's Footprint field, and U1's Footprint
    field in the schematic, both in the placed instance and in the cached
    symbol copy.
    Proven inert: the netlist's nets section is identical before and after (8
    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
    [ldo_bringup_board_ee372.kicad_sch]
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2026-09-30 Add banana jacks, SMAs, test points, and current-sense resistors
    Replaces the J1 screw terminal with banana jacks: J1 VIN, J2 and J7
    GND, J3 IBIAS, J4 VOUT.
    Splits the supply and output with 100m resistors: R4 from VDD to the
    new VDD_LDO net on the chip's supply pins, and R3 from the new VOUT_LDO
    net on pins 21-22 out to VOUT.
    Adds C6 1u, C7 100n and C9 0.1n on VDD, and the VIN_SMA (J5) and
    VOUT_SMA (J6) edge-launch SMAs, coupled through C8 10u from VDD_LDO
    and C10 10u from VOUT_LDO. C5 is now populated.
    Adds eight Keystone 5005-5009 through-hole test points, TP1-TP8, on
    MD, IBIAS, VIN, VDD_LDO, VOUT_LDO, VOUT and two on GND.
    [ldo_bringup_board_ee372.kicad_sch]
2026-09-30 Remove the graphic divider lines from the schematic
    Deletes the nine polylines that boxed off the Inputs, Outputs,
    Decoupling and LDO sections. No parts, wires, labels or nets change.
    [ldo_bringup_board_ee372.kicad_sch]
2026-09-30 Add a PWR_FLAG on the VDD_LDO net
    R4 feeds VDD_LDO from VDD, but ERC does not count a resistor as a
    power source, so it flagged the chip's VDD pins as undriven. The flag
    clears that error. No parts or nets change.
    [ldo_bringup_board_ee372.kicad_sch]
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2026-10-01 Merge local schematic work with the switched load and save in KiCad 10
    Schematic:
    - Add C11 (100u) and D1 (Schottky) between VDD and GND
    - Connect the switched load to VOUT and remove banana jacks J8 and J9
    - Add a fifth load branch: Q5, R13 (200), R14 (10k)
    - Change R10 from 100 to 67 and R12 from 200 to 100
    - Add test points TP9 to TP13 on VG0 to VG4
    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
    [ldo_bringup_board_ee372.kicad_sch]
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2026-10-02 Add project libraries for the load FETs and the mode switch
    Q1 to Q6 referenced a symbol library and a footprint library that were
    not in the repo. Both now exist in the project and are registered in the
    library tables.
    - switched_R_load_symlib.kicad_sym holds the FDV305N symbol, copied from
    the copy stored in the schematic.
    - FDV305N.pretty/SOT95P240X111-3N is KiCad's stock hand-solder SOT-23
    under the name the FETs already use.
    - SW_SPDT_CK_JS102011SAQN is KiCad's stock footprint for the C&K switch,
    pointed at a model in the gitignored 3dshapes folder and rotated to sit
    on its pads. A fresh clone shows the switch without a body.
    ERC library issues go from 12 to 0.
    Co-Authored-By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
2026-10-02 Assign footprints and part fields, switch C11 to an electrolytic
    Same 65 parts and 35 nets as before. No wiring changed.
    Schematic edits by Luke:
    - C11 is now a polarized capacitor symbol, plus side on VDD.
    - D1 value reads D_proc.
    Field edits by Claude:
    - Footprints on C1 to C11, D1, R1 to R4 and SW1, which had none.
    - Manufacturer, part number, DigiKey link, datasheet and description on
    the 53 parts in the BOM.
    - Q1 to Q6 value FDV305N, to match their part number field.
    - R5 value 53.6 and R10 value 66.5, the nearest values in stock.
    - Stale 249 and 124 ohm part fields on R5, R6, R10, R12, R13 replaced.
    J8, J9, R15 and R16 still have no footprint. J10 still has a logo
    footprint.
    Co-A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
    [ldo_bringup_board_ee372.kicad_sch, mcu_conn.kicad_sch]
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2026-10-02 Add Teensy 4.1, current sensing, a 5 V input and MD jumpers
    The netlist goes from 66 parts and 28 nets to 105 parts and 79 nets.
    Schematic edits by Luke
    - U2, a Teensy 4.1 on socket strips, replaces the MCU headers. Pins 2 to 6
    go to VG0 to VG4 through 0 ohm links R22 to R26. Pin 7 goes to the Q6 gate
    through jumper J9. Pins 10 to 13 carry the SPI labels. A1 and A2 read the
    two current-sense outputs.
    - U3 and U4, INA190A5 amplifiers across shunts R4 and R3, through 0 ohm
    links R29 to R32. Each output has a 1k and 100n filter (R27 with C12,
    R28 with C15).
    - J8 is now a +5V banana jack to the Teensy VIN, with C16 to C19 and
    Schottky D2 from +5V to GND.
    - A +3V3 rail from the Teens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
    [ldo_bringup_board_ee372.kicad_sch, mcu_conn.kicad_sch, tmp_sense.kicad_sch]
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2026-10-02 Add input filters to both current-sense amplifiers and rework the buffer power
    - R29 to R32, in series with the INA190 inputs, change from 0 ohm to 100 ohm,
    and C24 and C25 (100n) go across each amplifier's IN+ and IN-. With the
    100 ohm resistors that is an 8 kHz differential filter on each.
    - Buffer sheet. JP4 BUF_EN (2-pin header) replaces J14 between +5V and the
    BUF634A's V+. C23 becomes the 10u 1206 KEMET part, now from V+ to GND. The
    buffer's labels are global now, and R16 joins the buffer output to the VDD
    side of R4 (SHUNT_IN_A).
    - One stub wire and its junction removed on the top sheet.
    The netlist goes from 113 parts and 85 nets to 115 parts and 84 nets. ERC
    shows 1 error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
    [buffer.kicad_sch, ldo_bringup_board_ee372.kicad_sch, mcu_conn.kicad_sch]
2026-10-02 Add a power flag on the buffer's V+ net
    A PWR_FLAG on the V+ side of JP4 tells ERC that U5's V+ is powered from +5V
    once the jumper cap is on. ERC goes from 1 error to 0. Parts and nets are
    unchanged at 115 and 84.
    [buffer.kicad_sch]
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2026-10-03 Finish the BUF602 buffer, add M3 mounting holes, direct-couple the SMAs
    The netlist goes from 114 parts and 89 nets to 116 parts and 84 nets.
    ERC shows 0 errors and 37 warnings.
    - Buffer sheet. ls1031's J16, J17 and J18 removed. The BUF602 (U6) now
    uses the top-sheet SMAs, J13 on its input (VSIG) and J14 on its output
    (VSIG_BUF, was J15), both now the edge-mount Samtec part. Its output
    reaches the chip's VDD pins through R34 (2.2 ohm) onto SHUNT_IN_B. V+
    comes from +5V through jumper J12 BUF_EN.
    - The buffer's supply caps renumbered to C26 (4.7u) and C27 (0.1u), so
    C24 and C25 are the INA190 input filter caps again.
    - C8 and C10 removed. J5 now connects dir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
    [buffer.kicad_sch, ldo_bringup_board_ee372.kicad_sch]
2026-10-03 Put the SMA coupling caps back on J5 and J6
    C8 (10u) goes back between J5 and VDD_LDO (SHUNT_IN_B), and C10 (10u)
    between J6 and VOUT_LDO (SHUNT_OUT_A), both the 1206 KEMET part. A 50 ohm
    instrument on either SMA then sees only the ripple and draws no DC from the
    chip, and J6 is the AC-coupled VOUT output the guidelines ask for.
    Into 50 ohm the corner is 318 Hz.
    118 parts, 86 nets, ERC 0 errors.
    [ldo_bringup_board_ee372.kicad_sch]
2026-10-03 Add noise amplifier sheet, fill part fields, consolidate 10u and 100n caps
    Noise amplifier: OPA4388 with three x11 stages, outputs at x121 and x1331
    on J16 and J17, enabled by J15. Footprints and part fields on all its parts.
    C2 moves to the same 0805 100n as the other 0.1u caps. Every 10u except the
    C3 and C4 compensation pair moves to the 10% Murata GRM319R61E106KA12D.
    [ldo_bringup_board_ee372.kicad_sch, mcu_conn.kicad_sch, noise_amp.kicad_sch]
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2026-10-03 Replace J15 noise enable header with 0 ohm R44
    [noise_amp.kicad_sch]
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2026-10-03 Change noise amp feedback to 9k and outputs to 0 ohm, add NR jack and test point
    Noise amplifier sheet:
    - R16, R35, R38 changed from 10k to 9k
    - R39, R40 (49.9 ohm) removed; R49, R50 (0 ohm) placed between the U5
    stage outputs and C36, C37
    - J16, J17 values renamed NOISE_X100 and NOISE_X1000
    Top sheet:
    - TP30 added on NR
    - J15 banana jack added, joined to NR through R39 (0 ohm, DNP)
    - SW1 value renamed MD_SW
    [ldo_bringup_board_ee372.kicad_sch, noise_amp.kicad_sch]
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2026-10-03 placemtn and some schematic chagnes but might need to fix
    [ldo_bringup_board_ee372.kicad_pcb, ldo_bringup_board_ee372.kicad_sch]
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2026-10-04 Schematic freeze: add C10, probe headers, buffer link and Teensy taps
    SCHEMATIC FROZEN at this commit. 164 parts, 108 nets, ERC 0 errors.
    All remaining work is layout. Do not change the schematic without
    telling the group.
    - C10 (10u) back between VOUT_LDO and the J6 SMA
    - J18 VIN_PROBE, J19 VREF_PROBE, J20 VOUT_PROBE: 2-pin headers with
    pin 1 on VDD_LDO, NR, VOUT_LDO and pin 2 on GND
    - IBIAS and NR labels changed from local to global
    Buffer sheet:
    - R40 (0 ohm) in series between R34 and VDD_LDO
    MCU sheet:
    - J21 to J25, VG0_PROBE to VG4_PROBE: 2-pin headers with pin 1 on
    VG0 to VG4 and pin 2 on GND
    - R51, R52, R53 (0 ohm, DNP) from Teensy pins 23, 22, 21 to MD,
    IBIAS, NR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
    [buffer.kicad_sch, ldo_bringup_board_ee372.kicad_sch, mcu_conn.kicad_sch]
2026-10-04 Update PCB from the frozen schematic
    Update PCB from Schematic run against the frozen schematic. The PCB now
    has the same 164 parts, footprints, values and pad nets as the
    schematic, and DRC reports 0 schematic parity issues.
    - 23 sub-sheet resistors swapped from 0805 to 0603 footprints
    - C10, R40, R51 to R53 and J18 to J25 added, not yet placed
    - TP15 to TP19 restored
    - J18, R51, R52 and a stray second QFN footprint removed, since the
    schematic has no matching symbols
    Existing tracks and placement are otherwise as in b8ac7ff. Layout is
    not finished and DRC still reports errors.
    [ldo_bringup_board_ee372.kicad_pcb]
2026-10-04 Schematic changes after the freeze: drop 14 test points, add R54, move input caps
    The schematic changed after the freeze commit f5ce739. It now has 151
    parts and 109 nets. ERC 0 errors.
    - Removed TP9 to TP13 and TP15 to TP19 (on VG0 to VG4) and TP22 to TP25
    (on the four shunt nodes)
    - Added R54 (0 ohm, 0805, DNP) between the J3 IBIAS jack and the IBIAS
    net at U1 pin 5
    - C6, C7, C9 and C11 moved from VDD (SHUNT_IN_A) to VDD_LDO
    (SHUNT_IN_B), the chip side of the R4 shunt
    [ldo_bringup_board_ee372.kicad_sch, mcu_conn.kicad_sch]
2026-10-04 First pass of the layout, fully routed
    All 151 parts placed inside the 100 x 100 mm outline and every net
    routed: 786 track segments, 127 vias. DRC reports 0 errors, 0
    unconnected items and 0 schematic parity issues. 137 warnings remain,
    all silkscreen.
    - L2: one GND zone. L3: zones for +5V, +3V3, VDD and VDD_LDO
    - The six edge-mount SMAs sit with their edge line on the board outline
    - Design rules: minimum clearance and minimum track width set to
    0.15 mm, the class minimum in the EE372B guidelines
    [ldo_bringup_board_ee372.kicad_pcb]
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2026-10-04 Add R55 in series with C11
    R55 (0 ohm, 0805, fitted) sits between C11 (100u) and VDD_LDO. Lifting
    it takes C11 off the rail that R4 measures. 152 parts, 110 nets, ERC 0
    errors.
    [ldo_bringup_board_ee372.kicad_sch]
2026-10-04 Layout: place R55, move R54 and R39 next to U1, set the 1.6 mm stackup
    - R55 placed and routed between C11 and VDD_LDO
    - R54 and R39 moved close to U1, so the tracks from the J3 and J15
    jacks end at the jumpers
    - Physical stackup set to JLCPCB JLC04161H-7628: 0.035 / 0.2104 /
    0.0152 / 1.065 / 0.0152 / 0.2104 / 0.035 mm, 1.6062 mm with mask
    - Zones refilled
    DRC: 0 errors, 0 unconnected items, 0 schematic parity issues, 137
    silkscreen warnings. Still to do: ground test points near each signal
    test point, and board silkscreen text.
    [ldo_bringup_board_ee372.kicad_pcb]
2026-10-04 Add first silkscreen items: logo, board title and names
    - LOGO footprint on F.Silkscreen, 5.7 x 8.5 mm, marked not in
    schematic and excluded from the BOM and position files
    - Board text: "EE372B LDO Bringup PCB", an underline, and the four
    author names
    - Small routing edits: 796 track segments and 128 vias, up from 786
    and 127
    silkscreen warnings. Most of the silkscreen is still to do.
    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
    [ldo_bringup_board_ee372.kicad_pcb]
2026-10-04 Move C11 to VDD, remove R55, widen the analog tracks
    Schematic: R55 removed. C11 pin 1 moves from VDD_LDO (through R55) to VDD,
    the J1 side of R4. 151 parts, 109 nets, ERC 0 errors.
    PCB:
    - C11 moved to (114.5, 59.75), R55 footprint removed
    - VOUT_LDO widened from 0.3 to 0.7 mm
    - VSIG and VSIG_BUF widened from 0.3 to 0.6 mm, the R34 to R40 link and
    the R40 stub onto VDD_LDO to 0.7 mm
    - J6 output and the noise amplifier input, outputs, stage links, supply
    and 2.5 V reference widened from 0.3 to 0.6 or 0.7 mm
    - U3 sense tracks from R4 to R31 and R32 rerouted as a pair, R20 to R4
    links widened from 0.15 to 0.7 mm
    - J12 moved to (126.25, 117.75), TP4 to (159.25, 83.0), R29 0.25 mm left
    - V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
    [ldo_bringup_board_ee372.kicad_pcb, ldo_bringup_board_ee372.kicad_sch]
2026-10-04 Layout: move the left-edge connectors, mounting holes and TP20
    - J1, J7, J8 banana jacks and the J13, J14 SMAs moved along the left edge
    - J2 moved 3 mm left, D2 and C16 moved, TP20 (GND) moved to (115, 116.5)
    - Mounting holes now at (105.25, 55), (194.75, 55), (105.25, 146) and
    (194.75, 146)
    - VSIG and VSIG_BUF rerouted to the moved SMAs
    - Top-layer GND tracks between the J2 and J7 jack pins removed, the pins
    connect through the In1 plane
    - +5V and VDD pour outlines on In2.Cu adjusted
    Schematic unchanged. DRC 0 errors, 0 unconnected, schematic parity 0.
    [ldo_bringup_board_ee372.kicad_pcb]
2026-10-04 Checkpoint: add GND pours on F.Cu and B.Cu
    - GND zone on F.Cu and on B.Cu, each covering the board 0.5 mm inside the
    edge, 0.5 mm clearance
    - TP2 (IBIAS) moved 0.75 mm, IBIAS and nearby GND tracks rerouted
    No stitching vias added yet. Schematic unchanged.
    DRC 0 errors, 0 unconnected, schematic parity 0.
    [ldo_bringup_board_ee372.kicad_pcb]
2026-10-04 Add 143 GND stitching vias between the F.Cu and B.Cu pours
    Placed by script on a 5 mm grid, only where both outer GND pours already
    have copper, 0.45 mm inside the pour edge and 0.8 mm clear of every pad
    and existing via. 0.6 mm pad, 0.3 mm drill. Zones refilled.
    Parts, tracks, existing vias and zone outlines are unchanged.
    Vias 128 to 271. DRC 0 errors, 0 unconnected, schematic parity 0.
    [ldo_bringup_board_ee372.kicad_pcb]
2026-10-04 Add 189 more GND vias: return vias at layer changes, tighter stitching
    Placed by script, only where both outer GND pours already have copper.
    0.6 mm pad, 0.3 mm drill. Zones refilled.
    - 32 vias within 2 mm of signal and power vias that had no ground via
    nearby. 28 of 67 such vias still have none, no legal spot exists.
    - 157 vias on a 1.25 mm grid wherever the nearest ground via or pin was
    over 3.2 mm away.
    Pour area over 5 mm from a ground via: F.Cu 10.9% to 1.2%, B.Cu 17.1%
    to 4.2%. Parts, tracks, existing vias and zone outlines are unchanged.
    Vias 271 to 460. DRC 0 errors, 0 unconnected, schematic parity 0.
    [ldo_bringup_board_ee372.kicad_pcb]
2026-10-04 Checkpoint: add group number and date to the silkscreen
    One new F.SilkS text, "Grp 3" and "10/4/2026". Nothing else changed.
    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
    [ldo_bringup_board_ee372.kicad_pcb]
2026-10-04 Move ground test points TP20, TP21 and TP8 next to TP26, TP6 and TP4
    TP20 to (115.0, 117.5), TP21 to (169.5, 93.25), TP8 to (155.0, 84.75),
    each within 4.6 mm of the signal test point it serves. Three GND stub
    tracks that ended on the old pads and three GND stitching vias under the
    new pads removed. Zones refilled.
    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
    [ldo_bringup_board_ee372.kicad_pcb]
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2026-10-04 Place six of the new ground test points beside their signal test points
    TP23 by TP1, TP24 by TP27, TP33 by TP14, TP22 by TP3, TP25 by TP28 and
    TP31 by TP2, each 4.25 to 4.93 mm away. Four GND stitching vias that sat
    under the new pads removed. Zones refilled. TP32 left parked.
    Tracks unchanged. DRC 0 errors, schematic parity 0.
    [ldo_bringup_board_ee372.kicad_pcb]
2026-10-04 Place TP32, move TP4, TP8 and J19, reroute around them
    - TP32 (GND) placed at (165.25, 111.75) by TP7 and TP29, with the J15
    jack track rerouted to make room
    - TP8 (GND) moved to (152.25, 85.25), between TP4 and TP30
    - TP4 moved to (157.0, 85.25), TP7 nudged, J19 moved 4.75 mm up with its
    NR track
    - GND vias around those parts moved or removed
    Eleven of the twelve signal test points now have a ground test point
    within 5 mm. DRC 0 errors, 0 unconnected, schematic parity 0.
    [ldo_bringup_board_ee372.kicad_pcb]
2026-10-04 Add three spare through-hole pads, TP35 to TP37
    Keystone test point footprints valued SP1, SP2 and SP3, marked DNP and
    left unconnected, placed along the top edge at y = 55.5. GND stitching
    vias near them moved, four added and one removed.
    161 parts, 112 nets. DRC 0 errors, 0 unconnected, schematic parity 0.
    ERC 0 errors.
    [ldo_bringup_board_ee372.kicad_pcb, ldo_bringup_board_ee372.kicad_sch]
2026-10-04 Silkscreen cleanup, move J20 and TP27, reroute near the Teensy
    - Reference labels moved off pads and other silkscreen, H1 and H3 labels
    moved inside the board edge. DRC warnings 159 to 54.
    - J20 (VOUT probe header) moved to (161.5, 93.04) and rotated 90 degrees,
    with its VOUT_LDO track
    - TP27 moved 0.75 mm
    - MD, VDD, VOUT_LDO sense, +5V and +3V3 tracks rerouted near the Teensy,
    eight vias moved, two GND vias added
    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
    [ldo_bringup_board_ee372.kicad_pcb]
2026-10-04 Move the C11, J1, J2 and J17 reference labels
    Silkscreen only. Parts, tracks, vias and zones unchanged.
    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
    [ldo_bringup_board_ee372.kicad_pcb]
2026-10-05 Put connector, jumper and test point names on the silkscreen
    The Value text of all 52 J, TP and SW parts moved from F.Fab to
    F.Silkscreen at 0.8 mm. Eight extra texts added and parked to the right
    of the board for placement by hand (1.8V MAX, 5.5V MAX, polarity marks,
    HI and LO).
    Parts, tracks, vias, pads and zone copper unchanged. DRC 0 errors.
    [ldo_bringup_board_ee372.kicad_pcb]
2026-10-05 Place the silkscreen names, voltage limits and polarity marks
    - Net names dragged clear of pads on every connector, jumper and test
    point
    - "1.8V MAX" and "+" at the VIN jack J1, "-" at the GND jacks J2 and J7
    - "+" and "5.5V MAX" at the 5V jack J8, "HI" and "LO" at the ends of SW1
    - J21 to J25 names hidden and replaced with VG0 to VG4 texts
    Silkscreen only. DRC 0 errors, 0 unconnected, schematic parity 0.
    [ldo_bringup_board_ee372.kicad_pcb]
2026-10-05 Add a Pin Defaults sheet with the MD pin table
    New hierarchical sheet pin_defaults.kicad_sch, text only. It states how
    the MD pin (pin 29) is set by SW1 through R2 with J10 fitted, or by the
    Teensy through Q6 with J9 and J11 fitted, and that HI is high power mode
    and LO is low power mode.
    No parts or nets change. PCB unchanged. ERC 0 errors, DRC 0 errors,
    schematic parity 0.
    [ldo_bringup_board_ee372.kicad_sch, pin_defaults.kicad_sch]
2026-10-05 Add four GND vias along y = 102.95 and move one
    GND vias added at x = 171.5, 176.5, 181.25 and 186.25. The GND via near
    (189.1, 105.7) moved to (189.0, 106.25).
    Parts and tracks unchanged. DRC 0 errors, 0 unconnected, schematic
    parity 0.
    [ldo_bringup_board_ee372.kicad_pcb]
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2026-10-05 Add R55, a 0 ohm link between VOUT_LDO and a new VNOISE net
    Schematic: R55 (0 ohm 0805, fitted) has pin 2 on VOUT_LDO and pin 1 on a
    new net, VNOISE. C10 pin 1 (the J6 SMA coupling cap) and R44 pin 1 (the
    noise amplifier input link) move from VOUT_LDO to VNOISE.
    162 parts, 113 nets, ERC 0 errors.
    PCB: R55 placed at (191.625, 88.775). The old VOUT_LDO tracks to C10 and
    R44 are rerouted as VNOISE, 35.6 mm at 0.7 mm, 27 mm of it on B.Cu
    through two new vias. Seven GND vias added along x = 164.5.
    The exported Gerber, drill, CPL and report files in the repo predate
    this change.
    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
    [ldo_bringup_board_ee372.kicad_pcb, ldo_bringup_board_ee372.kicad_sch]
2026-10-05 Move the C10 reference label off the R55 pad
    Silkscreen only, one label. DRC warnings 40 to 38.
    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
    [ldo_bringup_board_ee372.kicad_pcb]
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
